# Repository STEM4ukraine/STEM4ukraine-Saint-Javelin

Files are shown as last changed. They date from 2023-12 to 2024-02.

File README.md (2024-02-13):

# STEM4ukraine-Saint-Javelin

A simple PCB with sound effects and the light show set off by pressing of the button!

An ideal school STEM project demonstrating use of GPIO for detecting button presses with software debouncing, charlieplexxing of multiple LEDs and playing music on the Piezo speaker.

The STEM4ukraine-Saint-Javelin-v1.ino firmware is written in the Arduino IDE and requires the Microcore attiny13 library, uses the 1.2MHz internal oscillator, with EEPROM retained and no bootloader. Feel free to modify it!

Celebrate Saint Javelin while you play the Ukrainian national anthem on the built in speaker!

The front of the PCB

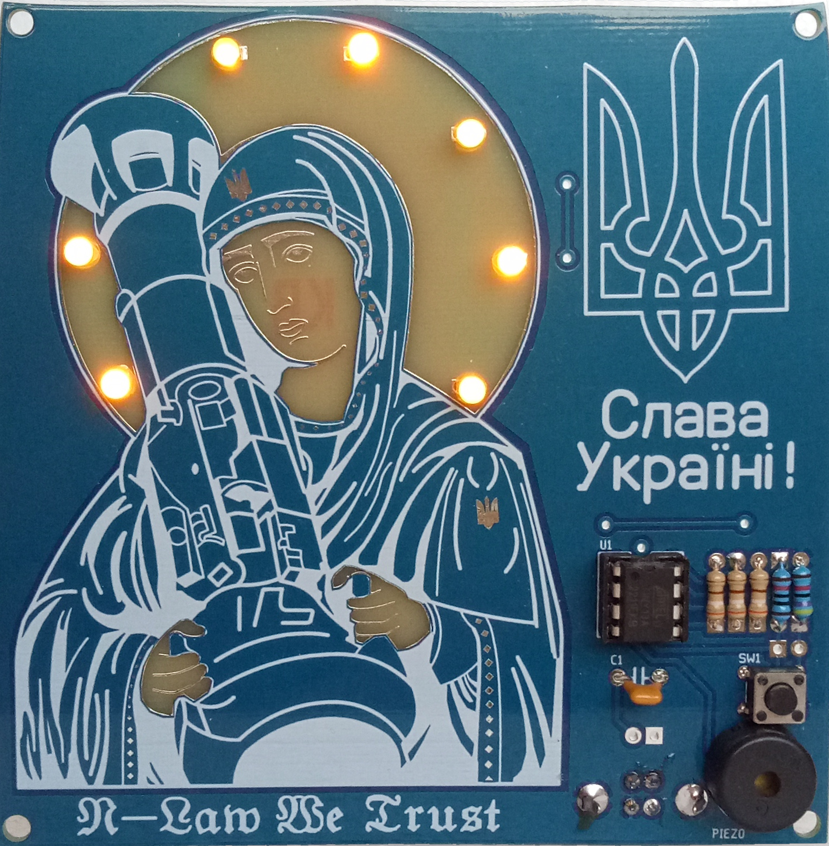
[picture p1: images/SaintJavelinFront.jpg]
prototype front


The rear of the prototype PCB

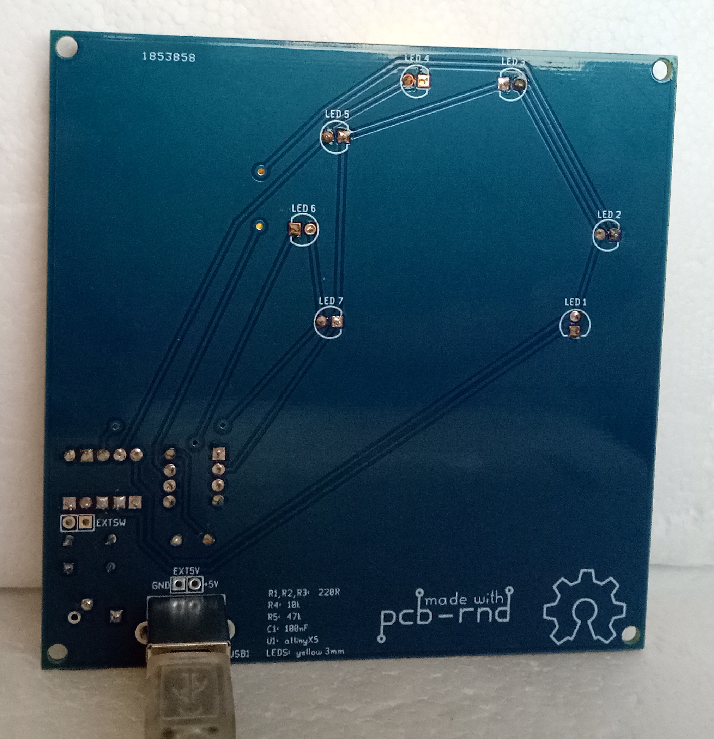
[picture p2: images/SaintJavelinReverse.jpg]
prototype back


The schematic

Schematic

Bill of materials:

- U1:  attiny13
- C1:  100nF
- R1,R2,R3:  220R
- R4:  10k
- R5:  47k
- LED1-7:  yellow 3mm LED
- SW1: momentary switch
- PIEZO:  piezo speaker
- USB1:  180 degree vertical through hole type B USB socket
- EXTSW:  optional 2.5mm header for external wiring for switch
- EXT5V:  optional 2.5mm header for external wiring for 5V power

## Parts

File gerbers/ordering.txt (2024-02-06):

dimensions 100mm x 100mm
silk white
mask blue
pads Pb/Sn

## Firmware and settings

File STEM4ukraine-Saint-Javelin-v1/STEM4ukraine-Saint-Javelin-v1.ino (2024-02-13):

/*
 *
 *   Copyright (C) 2024 STEM4ukraine
 *   Website https://github.com/STEM4ukraine
 *
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
 */

#include <avr/pgmspace.h>

// the code has been uploaded using a USB-ASP programmer 
// and the "USB-ASP slow (Microcore)" setting in the arduino IDE

// Microcore attiny13 selected
// using 1.2MHz internal oscillator
// EEPROM retained
// no bootloader

// notes B up to A defined as
// MSB XXXX0000 as pitch index into the (note period in uS) array
// LSB 0000XXXX as note duration

#define A_2 98 //6*16 + 2  // 568  // freq 880
#define A_1 97 //6*16 + 1  // 568  // freq 880
#define A_0 96 //6*16 + 0  // 568  // freq 880
#define G1  81 //5*16 + 1  // 638  // freq 784
#define G0  80 //5*16 + 0  // 638  // freq 784
#define FS3 67 //4*16 + 3  // 676  // freq 740
#define FS2 66 //4*16 + 2  // 676  // freq 740
#define FS1 65 //4*16 + 1  // 676  // freq 740
#define FS0 64 //4*16 + 0  // 676  // freq 740
#define E1  49 //3*16 + 1  // 758  // freq 659
#define E0  48 //3*16 + 0  // 758  // freq 659
#define D1  33 //2*16 + 1  // 851  // freq 587
#define D0  32 //2*16 + 0  // 851  // freq 587
#define CS1 17 //1*16 + 1  // 902  // freq 554
#define CS0 16 //1*16 + 0  // 902  // freq 554
#define B3  3  //0*16 + 3  // 1012 // freq 494
#define B2  2  //0*16 + 2  // 1012 // freq 494
#define B0  0  //0*16 + 0  // 1012 // freq 494

#define NOTE_DELAY_MS 10 // between notes

// first 8 bars of anthem is first 18 notes, followed by first 14 notes, then 19th note played twice

static const uint16_t note_periods[7] PROGMEM = {1012, 902, 851, 758, 676, 638, 568};

static const uint8_t notesPDtest[8] PROGMEM = {B0, CS0, D0, E0, FS0, G0, A_0, G0};

// first 8 bars
static const uint8_t notes12PD[18] PROGMEM = {FS2, FS0, FS0, E0, FS0, G0, A_2, G0, FS1, E1, D1, FS1, CS1, FS1, B2, CS0, D1, E1};

// 9th-12th bars + 13 into next 3 bars
static const uint8_t notes34PD[18] PROGMEM = {CS1, CS1, FS0, E0, D0, CS0, B0, CS0, D0, B0, CS1, CS1, D1, D1, E1, E1, FS3, FS3};

// final 9 notes of 15-16th bars
static const uint8_t notes4PD[9] PROGMEM = {FS1, CS1, FS1, B2, CS0, D0, E0, FS0, G0};

// next 4 bars + repeat first 11 into next 3 bars
static const uint8_t notes56PD[18] PROGMEM = {A_2, A_0, A_1, FS1, E1, E1, A_0, G0, FS0, E0, D1, D1, E1, E1, FS2, E0, FS1, G1};

// final 5 notes = end of 7th, 8th bar, i.e. index 
static const uint8_t notes6PD[5] PROGMEM = {FS1, CS1, FS1, B3, B3};

uint8_t led = 0;
uint8_t button = 0;

void setup() {
  pinMode(0, OUTPUT);
  pinMode(1, OUTPUT);
  pinMode(2, OUTPUT);
  pinMode(3, OUTPUT);
  pinMode(4, OUTPUT);
  pinMode(5, INPUT);
}

void turn_on_LED(int duration_us) { // n = 0-6
  switch (led%7) {
    case 0:
      PORTB = 0b00001101;
      break;
    case 1: 
      PORTB = 0b00001011;
      break;
    case 2: 
      PORTB = 0b00000111;
      delayMicroseconds(duration_us);
      PORTB = 0b00000001;
      break;
    case 3: 
      PORTB = 0b00001010;
      break;
    case 4: 
      PORTB = 0b00000110;
      delayMicroseconds(duration_us);
      PORTB = 0b00000010;
      break;
    case 5: 
      PORTB = 0b00001100;
      break;
    case 6:
      PORTB = 0b00000110;
      break;
    default:
      break;
  }
  delayMicroseconds(duration_us);
}

void turn_off_LEDs(int duration_us) {
  PORTB &= ~0b00001111;
  delayMicroseconds(duration_us);
}
 
void cycle_LEDs_once(int onduration_us, int offduration_us) {
  for (led = 0; led < 7; led++) {
      turn_on_LED(onduration_us);
  }
  turn_off_LEDs(offduration_us); // accentuate off time
  turn_off_LEDs(offduration_us);
  turn_off_LEDs(offduration_us);
}

void cycle_LEDs_n_times(int onduration_us, int offduration_us, int n) {
  for (int j = 0; j < n; j++) {
    cycle_LEDs_once(onduration_us,offduration_us);
  }
}

byte poll_button() {
  button = button|(analogRead(A0) < 1000);
  return button;
}

void pulse_LEDs() {
  int ramp_cycles = 5;
  int cycles = 20;
  int led_off_max_us = 234;
  int us_per_LED = 4;
  int i,k;
  for(k = 0; k < led_off_max_us && !poll_button(); k += 13) {
    for (i = 0; i < ramp_cycles; i++) {
      cycle_LEDs_n_times(us_per_LED,k,cycles);
    }
  }
  for(k = led_off_max_us; k > 0 && !poll_button(); k -= 13) {
    for (i = 0; i < ramp_cycles; i++) {
      cycle_LEDs_n_times(us_per_LED,k,cycles);
    }
  }
}

void play_note(const uint8_t * rawnote) {
  int periods;
  uint8_t k, raw_note, note_dur;
  uint16_t note_per, cycles, cycles_;

  raw_note = pgm_read_byte(rawnote);
  note_dur = raw_note & 0b00001111;
  periods = ((raw_note>>4) & 0b00001111);
  memcpy_P (&note_per, note_periods+periods, 2);

  // this would need modification for notes outside of the B4-A5 note range
  cycles = (0x82*500)/note_per; // just avoids overflow for B4-A5 note range
  turn_on_LED(2);
  for (k = 0; k < (note_dur+1); k++) {
    //turnOnLed(2);
    for (int i = 0; i < 3; i++) { // this, times overflow constrained cycles
      cycles_ = cycles;           // gives required duration
      while (cycles_ > 0) {
        PORTB |= (1 << PB4);
        delayMicroseconds(note_per);
        
        PORTB &= ~(1 << PB4);
        delayMicroseconds(note_per);
        cycles_--;
      }
    }
  }
  poll_button();
  led++;
  delay(NOTE_DELAY_MS);
}

void play_anthem() {
  char j;
  char raw_note;
  uint16_t note_dur, note_per;

//  for (j = 0; j < 8; j++) {
//    play_note(notesPDtest+j);
//  }

  // play first 18 notes and then the first 14 again
  for (j = 0; j < 32 && !poll_button(); j++) {
    play_note(notes12PD+(j%18));
  }

  // play last note twice
  for (j = 3; j < 5 && !poll_button(); j++) {
    play_note(notes6PD+j);
  }

  for (j = 0; j < 31 && !poll_button(); j++) {
    play_note(notes34PD+(j%18));
  }

  for (j = 0; j < 9 && !poll_button(); j++) {
    play_note(notes4PD+j);
  }

  for (j = 0; j < 29 && !poll_button(); j++) {
    play_note(notes56PD+(j%18));
  }

  for (j = 0; j < 5 && !poll_button(); j++) {
    play_note(notes6PD+j);
  }

}

// the main loop which repeatedly calls the LED lighting code, polls the button
// and plays the anthem if the button has been pressed
void loop() {

  button = 0;

  // allow break after every note, if button pressed.
  while(1) {
    if (poll_button()) {
      button = 0;
      delay(200); // debounce
      play_anthem();
      button = 0; // in case button pressed during anthem to finish it early
      delay(200); // debounce
    }
    pulse_LEDs();
  }
}

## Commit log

2023-12-20 Add prototype photos
2024-02-13 Add schematic
2024-02-13 Update README.md with schematic
2024-02-13 Update README.md with BOM
2024-02-13 Update README.md BOM
2024-02-13 Add schematic file and pcb layout files
2024-02-13 Add gerbers for PCB ordering
    [STEM4ukraine-Saint-Javelin-v1.GBL, STEM4ukraine-Saint-Javelin-v1.GBO, STEM4ukraine-Saint-Javelin-v1.GBS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]

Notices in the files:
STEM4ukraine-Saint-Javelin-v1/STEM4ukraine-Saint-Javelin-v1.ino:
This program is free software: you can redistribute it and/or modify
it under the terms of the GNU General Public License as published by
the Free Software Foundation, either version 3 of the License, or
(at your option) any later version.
